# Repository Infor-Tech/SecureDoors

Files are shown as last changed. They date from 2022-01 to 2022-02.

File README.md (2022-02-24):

# SecureDoors

Alarm for your door with SMS or call notification

## There are two versions of this project

1. main.ino
   1. Makes X calls as a notification
   2. Disarmed state is active until door is closed
2. alt.ino
   1. Sends an sms as a notification
   2. Disarmed state is active for declared time

### You can use those files to modify behaviour of this device

## Technical differences between those files

The main differences are in the `toggle_alarm` function. [`main.ino`](./main/main.ino) file has also a function called `hang_up_call` which does not appear in [`alt.ino`](./alt/alt.ino) file.

# What such device should do

- When door is opened (REED SWITCH IS OPENED)
  - Makes X calls (You specify duration and count of those)
  - Turns on a siren (You specify a delay between opening a door and toggling a siren and the duration of the alarm)
- When disarm button is pressed
  - Disarms the alarm

# Parts used for this project

- Arduino Nano (or UNO, It's basically the same)
- Reed Switch (Normally closed)
- Siren (Or any other sound emmiter working by applying voltage)
- SIM800L EVB 2.0 GSM module.
- 1CH Relay (Low level trigger)
- Pushbutton
- Battery, or any other power source (Prefferably 12V)
- Step-down converter (On output 5V and min. 2.2A)

# Libraries used for this project

- SoftwareSerial.h (https://www.arduino.cc/en/Reference/SoftwareSerial)
  - Note: This library is installed with Arduino IDE

# Schematics and diagrams

## Diagram

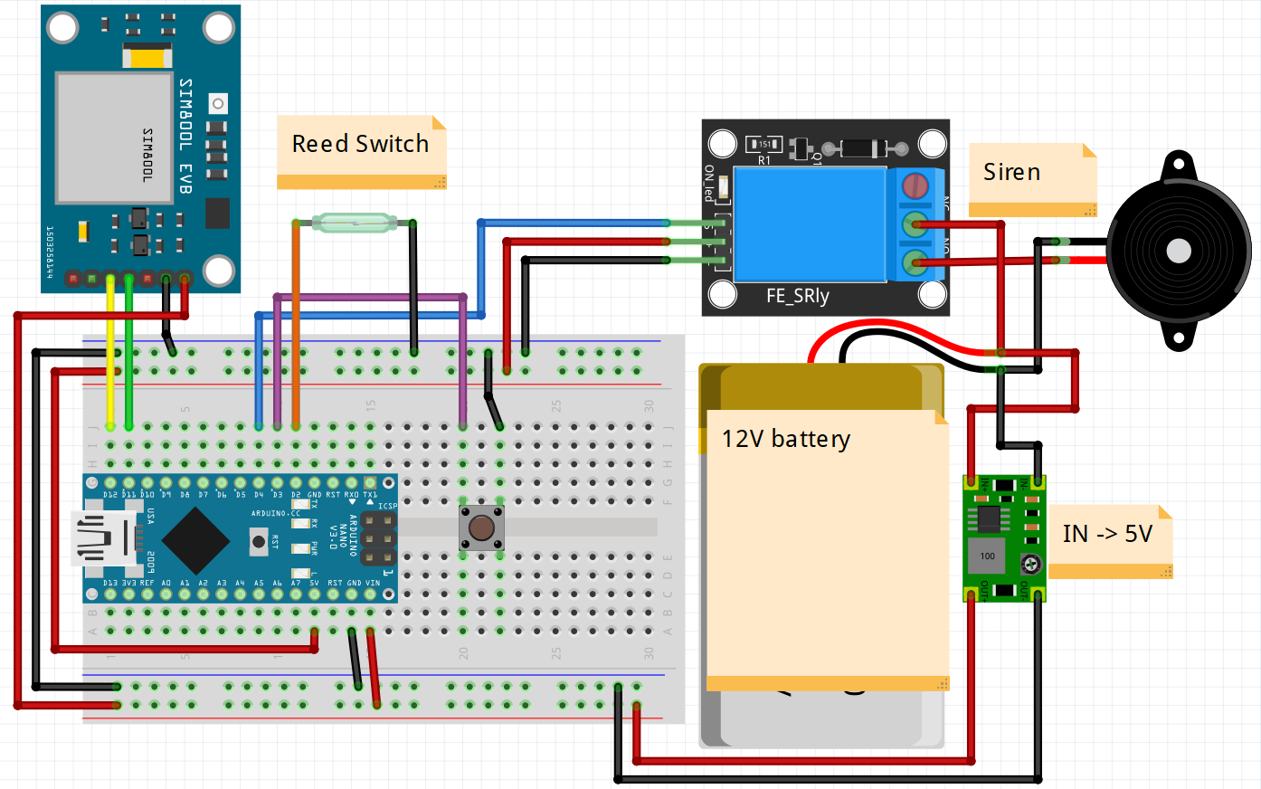
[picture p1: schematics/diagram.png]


## Schematics

Not yet released

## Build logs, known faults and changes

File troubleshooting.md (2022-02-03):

# SecureDoors Troubleshooting Manual

## Table of Contents:

1. [**Testing connections**](#Testing-connections)
2. [**Testing components**](#Testing-components)
    1. [Testing a reed switch and pushbutton](#Testing-reed-switch-and-pushbutton)
    2. [Testing an Arduino](#Testing-an-Arduino)
    3. [Testing a SIM800L EVB V2 module](#Testing-SIM800L-EVB-V2-module)
    4. [Testing a relay](#Testing-a-relay)
    5. [Testing a siren](#Testing-a-siren)
3. [**Debugging the code**](#Debugging-the-code)

# Testing connections

Necessary equipment to perform these actions:

- Multimeter with countinutiy beep

Check countinuity of each connection while following the [diagram or schematics](./schematics)



If everything is connected correctly, follow next steps.

# Testing components

It is possible, that the reason for your device not working is/are malufunctioning component/s. Perform these actions in order to check what is causing issues.

# Testing reed switch and pushbutton

The reason of your device not working might be false readings from those components. To check if that's the case you will need:

- Multimeter with countinutiy beep

Check how behaves a reed switch, Does multimeter beep when magnet is in contact with a reed switch? Does mulitimeter stop beeping when magnet is not in contact with a reed switch? If so, this part is working, as it should. If it's oposite you will need to change code in [main/main.ino](./main/main.ino). Add/remove "!" character standing in front of `digitalRead(REED_SWITCH)`.

Check how behaves the pushbutton. Mulitmeter should beep only when button is pressed.

If both of these components are working, follow next step, else replace those components and check if device is working. 

# Testing an Arduino

There is a possibility of your device not working because of malfunctioning arduino. To check if that's the case you will need:

- Led
- 220ohm resistor
- pushbutton
- breadboard
- jump wires
- usb cable

What we will check?

- Digital pins
- Serial connection

## **Checking digital pins**

Connect your arduino to an led like in this diagram:



And upload this code:

```ino
#define TESTED_PIN 2 // change this number when checking other pin

void setup() {
    pinMode(TESTED_PIN, OUTPUT);
}

void loop() {
    digitalWrite(TESTED_PIN, HIGH);
    delay(2000);
    digitalWrite(TESTED_PIN, LOW);
    delay(5000);
}
```

The output of this code should be an LED blinking. (2 seconds on, 5 seconds off). If that is the output on all digital pins, it means that arduino can apply voltage on those pins.

Now let's check if arduino can detect change on those pins. Connect your arduino to a pushbutton like in this diagram:



And upload this code:

```ino
#define TESTED_PIN 2 // change this number when checking other pin

void setup() {
    pinMode(TESTED_PIN, INPUT_PULLUP);
    pinMode(LED_BUILTIN, OUTPUT); // if your board does not have a builtinled, connect such to a pin 13
}

void loop() {
    if(!digitalRead(TESTED_PIN)) {
        digitalWrite(LED_BUILTIN, HIGH);
    } else {
        digitalWrite(LED_BUILTIN, LOW);
    }
}
```

The output of this code should be an led glowing only when button is pressed. Check all pins.

## **Checking serial connection**

If that works, check the Serial communication. Connect your arduino to the computer, upload this code and open Serial monitor on baud: 9600.

```ino
void setup() {
    Serial.begin(9600);
}

void loop() {
    while(Serial.available()) {
        Serial.println(Serial.read());
    }
}
```

After you open a serial monitor type something in a input box and click send. Arduino should reply with the same text as you sent.

# Testing SIM800L EVB V2 module

When your device is not making calls or does not send sms's as it should proceed with these steps. Otherwise you can skip this section.

Connect this module just like in SecureDoors diagrams and schematics ([schematics/diagram.png](./schematics/diagram.png) or [schematics/schematics.fzz](./schematics/schematics.fzz)).

**Note: This module needs power of 5V and at least of 2A to work properly. QuickCharge compatible phone chargers may not work for this purpose. Most problems with SIM800L are a result of not enough current being applied on this module.**

Upload this code:

```ino
#include <SoftwareSerial.h>
SoftwareSerial gsm_conn(11, 12);

void setup() {
    Serial.begin(9600);
    gsm_conn.begin(9600);
}

void loop() {
    while(Serial.available()) {
        gsm_conn.println(Serial.read());
    }

    while(gsm_conn.available()) {
        Serial.println(gsm_conn.read());
    }
}
```
Arduino will pass everything you send from serial monitor to SIM800L module.

### **Use those commands to check if this module works**
**`AT`** - The response should be: **`OK`**, if it's not, arduino is not communicating with this module.  
**`AT+CSQ`** - The response should be looking like this: **`+CSQ:24,0`**. First number indicates signal strength, greater is better, max is 31, 99 means it has no signal. Second number indicates Bit Error Rate. This number should be closer to 0  
**`AT+CERG?`** - The response should be looking like this **`CREG:1,4`**. Ideal reply is:

- **`+CERG:1,3`**
- **`+CERG:1,4`**
- **`+CERG:1,5`**
- **`+CERG:1,6`**

# Testing a relay.

Check at what level relay is triggered. Code was written for low level trigger relays. If your relay is triggered by high voltage replace in `main/main.ino` words `LOW` and `HIGH` with each other.

If that's not an issue check relay by connecting `+` or `VCC` and `IN` pins to 5V power source and `GND` pin to ground. In this state relay should not be triggered. Disconnect 5V from `IN` pin of an relay. Now it should be triggered.

# Testing a siren.

Apply sufficient voltage to siren and check if it makes a sound. Caution for your ears.

# Debugging the code

Build a device using SecureDoors [diagram and schematics](./schematics). Since arduino uno/nano do not support debugging natively paste this code into `main/main.ino` file. 

Into setup():

```ino
Serial.begin(9600);
```

Into loop():

```ino
Serial.print("Reed: ");
Serial.print(digitalRead(REED_SWITCH));
Serial.print("; Triggerable: ");
Serial.print(is_alarm_triggerable);
Serial.print("; Toggled: ");
Serial.print(is_alarm_toggled);
Serial.print("; Disarmed: ");
Serial.print(is_alarm_disarmed);
Serial.print("; Call: ");
Serial.println(is_call_made);
```

Open a serial monitor. You should see output like this:

```
Reed: 0; Triggerable: 1; Toggled: 0; Disarmed: 0; Call: 0
```

### **Explaination of the output**

First number indicates the state of a reed switch. 1 means that doors are open.<br>
Second number indicates the state of an alarm. It cannot be triggered when 0.<br>
Third number shows if alarm has been activated. 1 means yes.
Forth number shows if alarm is in a disarmed state. 1 means yes.
Fith number indicates that call has been made and wasn't hung up. 1 means yes.

### **Expected output**

When device turned on and alarm has not been activated output should look like:

```
Reed: 0; Triggerable: 1; Toggled: 0; Disarmed: 0; Call: 0
```

When the door is opened.

```
Reed: 1; Triggerable: 1; Toggled: 1; Disarmed: 0; Call: 0
```

After TIME_FOR_DISARMING (default: 15s)

```
Reed: 1; Triggerable: 1; Toggled: 1; Disarmed: 0; Call: 1
```

After pressing disarm button (doors should be open)

```
Reed: 1; Triggerable: 1; Toggled: 0; Disarmed: 1; Call: 0
```

When alarm was running for longer than ALARM_DURATION

```
Reed: 1 or 0; Triggerable: 0; Toggled: 0; Disarmed: 0; Call: 0
```

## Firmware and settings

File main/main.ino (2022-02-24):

/**
 * @file main.ino
 * @author Krystian Śliwiński (k.sliwinski@protonmail.com)
 * @brief SecureDoors, Alarm for your doors with call notification.
 * @version 0.1
 * @date 2022-01-30
 *
 * @copyright Copyright (c) 2022 Krystian Śliwiński, under MIT license.
 *
 * Parts used in this project:
 *      - Arduino Nano (or UNO, It's basically the same)
 *      - Reed Switch (Normally closed)
 *      - Siren (Or any other sound emmiter working by applying voltage)
 *      - SIM800L EVB 2.0 GSM module.
 *      - 1CH Relay (Low level trigger)
 *      - Pushbutton
 *      - Battery, or any other power source (Prefferably 12V)
 *      - Step-down converter (On output 5V and min. 2.2A)
 *
 */

// gsm module
#include <SoftwareSerial.h>
SoftwareSerial gsm_conn(11, 12); // 11 -> TX; 12 -> RX

// pins
#define REED_SWITCH 2
#define DISARM_SWITCH 3
#define SIREN 4

// config
#define TIME_FOR_DISARMING 15000 // in ms; [default: 15s (15000ms)]
#define ALARM_DURATION 180000    // in ms, add time for disarming; [default: 3min - TIME_FOR_DISARMING (180000ms)]
#define CALL_DURATION 20000      // in ms [default: 20s (20000ms)]
#define CALL_COUNT 5             // default: 5

bool is_alarm_triggerable = true;

bool is_call_made = false;
byte made_call_count;
unsigned long when_call_made;

bool is_alarm_disarmed = false;

bool is_alarm_toggled = false;
unsigned long when_alarm_toggled;

/// Turns on a SIREN and makes call when door is opened and alarm is not disarmed and has not been disabled
void toggle_alarm()
{
    if (digitalRead(REED_SWITCH) && !is_alarm_disarmed && is_alarm_triggerable)
    {
        if (!is_alarm_toggled)
        {
            when_alarm_toggled = millis();
            is_alarm_toggled = true;
        }
        else if (millis() - when_alarm_toggled > TIME_FOR_DISARMING)
        {
            if (!is_call_made && made_call_count < CALL_COUNT)
            {
                if (made_call_count != 0)
                    delay(1000);
                gsm_conn.println("AT");
                delay(100);
                gsm_conn.println("ATD+ +48XXXXXXXXX;"); // replace X's with your phone number
                when_call_made = millis();
                is_call_made = true;
                made_call_count++;
            }
            digitalWrite(SIREN, LOW);
        }
    }
}

/// Hangs up a call and turns off a SIREN when alarm disarmed or when alarm was toggled for longer than specified.
/// When alarm was running for longer than specified, it is disabled and cannot be triggered, untill disarmed.
void turn_off_alarm()
{
    if (is_alarm_disarmed || (is_alarm_toggled && millis() - when_alarm_toggled > ALARM_DURATION))
    {
        if (is_call_made)
            gsm_conn.println("ATH");
        is_alarm_triggerable = is_alarm_disarmed; // when action toggled because of disarming an alarm, it can still be triggered
        is_call_made = is_alarm_toggled = false;
        made_call_count = 0;
        digitalWrite(SIREN, HIGH);
    }
}

void arm_or_disarm_alarm()
{
    if (!digitalRead(DISARM_SWITCH))
    {
        is_alarm_disarmed = true; // disarming an alarm
        while (!digitalRead(DISARM_SWITCH))
        {
            // while pressed, wait and do nothing
        }
    }
    else if (!digitalRead(REED_SWITCH))
    {
        is_alarm_disarmed = false; // arming an alarm
    }
}

/// Hangs up a call when it is longer than specified
void hang_up_call()
{
    if (is_call_made && millis() - when_call_made > CALL_DURATION)
    {
        is_call_made = false;
        gsm_conn.println("ATH");
    }
}

void setup()
{
    pinMode(REED_SWITCH, INPUT_PULLUP);
    pinMode(DISARM_SWITCH, INPUT_PULLUP);
    pinMode(SIREN, OUTPUT);
    digitalWrite(SIREN, HIGH);
    gsm_conn.begin(9600);
}

void loop()
{
    arm_or_disarm_alarm();
    toggle_alarm();
    turn_off_alarm();
    hang_up_call();
}

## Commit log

2022-01-29 Added breadboard schematics
    [schematics.fzz]
2022-01-31 Fixed pushbutton connection
    [schematics.fzz]
